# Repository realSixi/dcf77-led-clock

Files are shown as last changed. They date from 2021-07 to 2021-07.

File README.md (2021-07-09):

# DCF77 LED Clock

A visualization for the DCF77 signal using 2 WS2812 / Neopixel LED Rings (60 and 24 LEDs). The DCF77 Signal is received via a Websocket Stream.

The intention is *not* to simple show the current time, but to show the single (bit) signals of the DCF77 signal.

Find more Information about DCF77 at Wikipedia: https://en.wikipedia.org/wiki/DCF77

YouTube: ESP8266 Projekt: DCF77 Visualisierung (https://www.youtube.com/watch?v=JKQQ1zitYd8)\
Video: https://www.youtube.com/watch?v=JKQQ1zitYd8

## Visualization

In the picture below the time is 20:33 (or 8:33). The 'white' pixels show the current time in the style of an analog clock: Minutes are at 33 and the hours are between 8 and 9 - like the clock-indicator of an analog watch.

Every "Block" is shown in alternating colors (yellow / blue). E.g. the first yellow block is the one-block of minutes (here 0100 = 4, means after the full circle the next one part of minute is 4).

There are 3 bits that are used as parity bits (green pixels in the image).

The second is indicated with a slightly lighter / darker pixel that's moving (hard to see in a still image).

### Limitations

This implementation does *not* always show the correct time:
- the 'white' indicators are only refreshed after a full circle (as intended by dcf77 protocol), but only if the parity bits are correct.
- if a partity bit is wrong, the indications 'lags' behind the real time
- due the source is a websocket... wrong data is really rare ;)
- if the websocket connection is interrupted: you'll be timeless. grap yourself a coffee and relax ;)

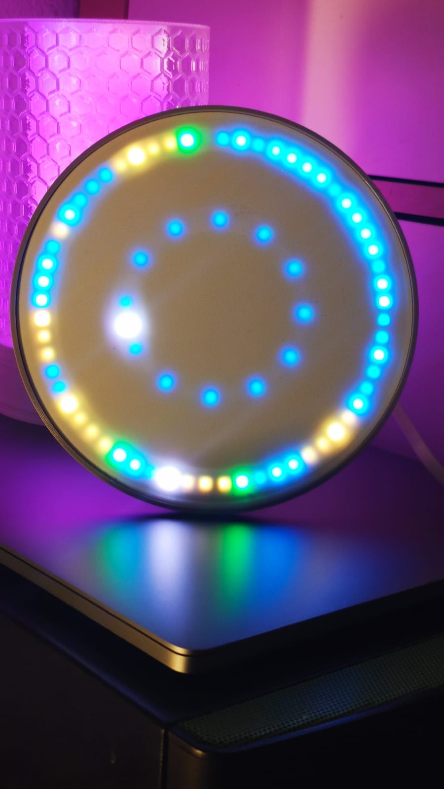
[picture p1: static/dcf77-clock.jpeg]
3D Printed Clock


## Hardware

### 3D Print

Find the STL Files in the [3D-Parts](./3d-parts) Folder. 

- Printed with a Prusa MK3S+ with PETG Filament and 0.6mm Nozzle
- The "Shader" is printed with white PETG 

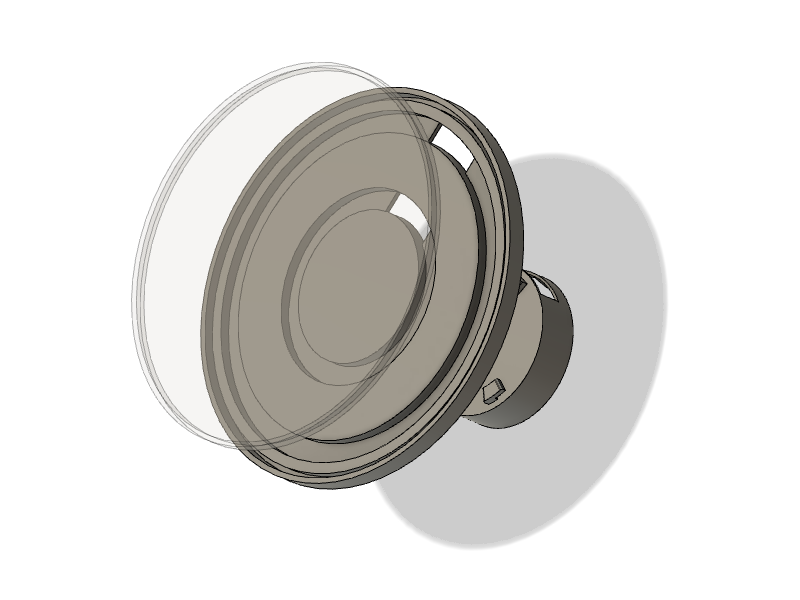
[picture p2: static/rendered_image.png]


### LEDs

There are multiple shops that deliver WS2812/Neopixel Rings (to Germany). Here is a short, uncomplete list. Just search for 'ws2812 ring' and you find a bunch of suppliers ;)

Solder the LED Rings together in a 'chain':
- LED 0-59 (the "minute" ring)
- LED 60-83 (the "hour" ring)

Data OUT of the large ring must be connected to Data IN of the small ring. Connect the Data IN Pin of the large ring to the ESP (default: D4) and the GNC/VCC accordingly.

#### 60 LED Ring

- https://www.funduinoshop.com/WS2812-LEDs-mit-60-Pixeln
- https://www.berrybase.de/sensoren-module/led/ws2812-13-neopixel/ringe/neopixel-ring-mit-60-ws2812-5050-rgb-leds
- https://de.aliexpress.com/w/wholesale-ws2812-ring-60.html

*Watch out! Some sellers offer only 1/4th of the Ring! So read the descriptions with care.*

#### 24 LED Ring

- https://www.funduinoshop.com/epages/78096195.sf/de_DE/?ObjectPath=/Shops/78096195/Products/F-5-3
- https://www.berrybase.de/sensoren-module/led/ws2812-13-neopixel/ringe/neopixel-ring-mit-24-ws2812-5050-rgb-leds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

## Software

### Setup

1. Rename the `credentials_example.h` in the root folder to `credentials.h` and set your WiFi credentials.
2. Set the LED_PIN if you use a different PIN than D4
3. Run with PlatformIO.

### Used Libraries / Tools

- PlatformIO http://platformio.org/
- FastLED: https://github.com/FastLED/FastLED
- WebSocket for Arduino: https://github.com/Links2004/arduinoWebSockets
- ArduinoJson: https://arduinojson.org/

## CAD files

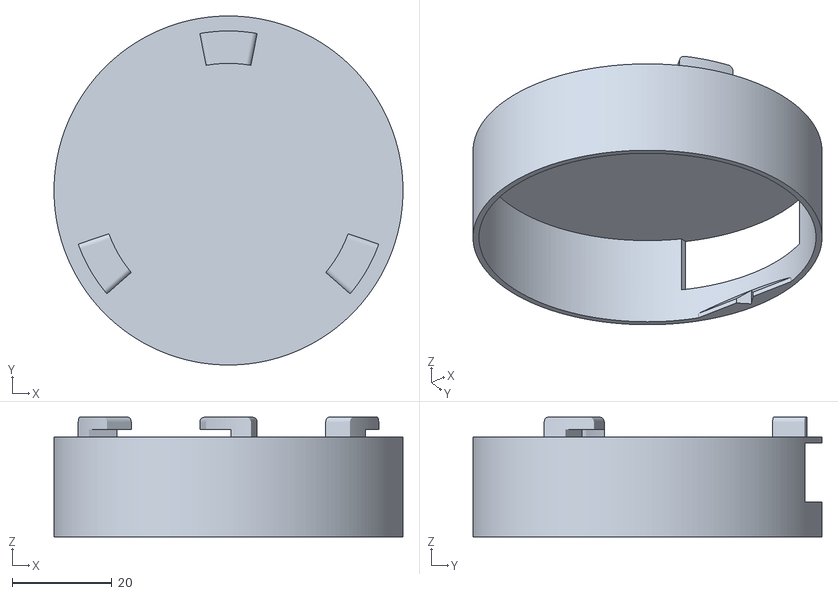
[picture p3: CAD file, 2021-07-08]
3d-parts/electronics_box.stl
70.0 x 70.0 x 24.0

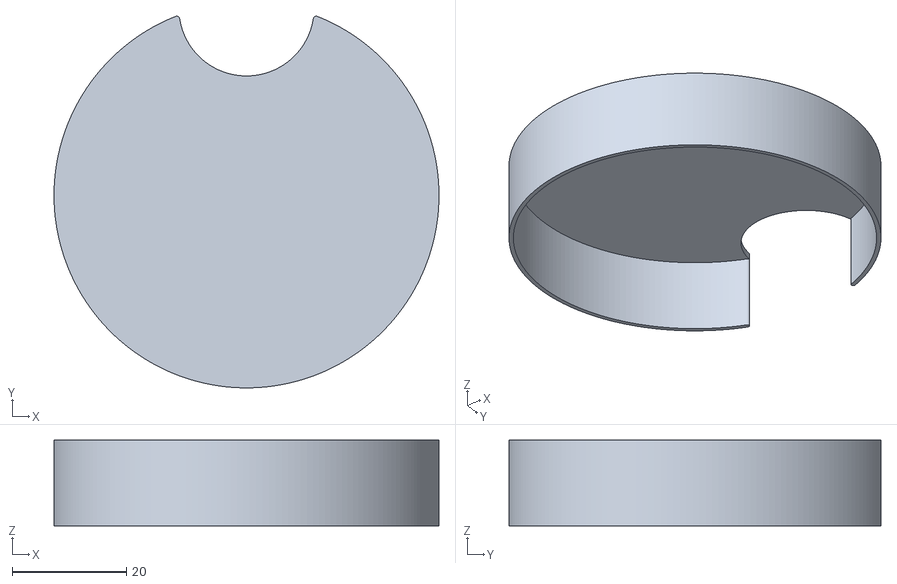
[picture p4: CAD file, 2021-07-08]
3d-parts/electronics_box_cap.stl
67.4 x 65.1 x 15.0

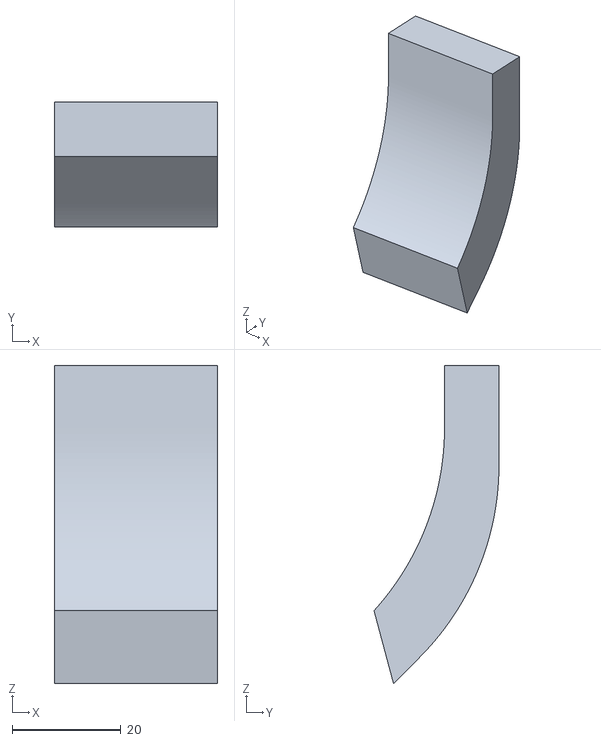
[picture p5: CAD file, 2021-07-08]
3d-parts/clock_desk_stand.stl
30.0 x 22.9 x 58.4

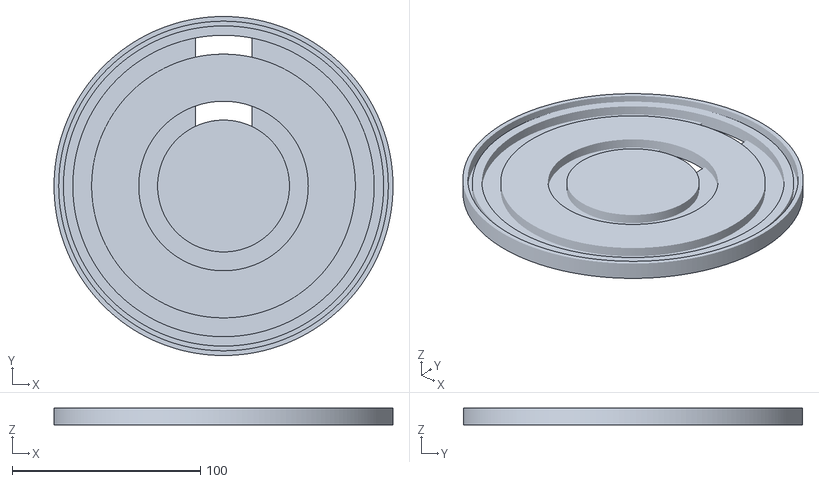
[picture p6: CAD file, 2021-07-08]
3d-parts/clock_led_holder.stl
180.0 x 180.0 x 9.00

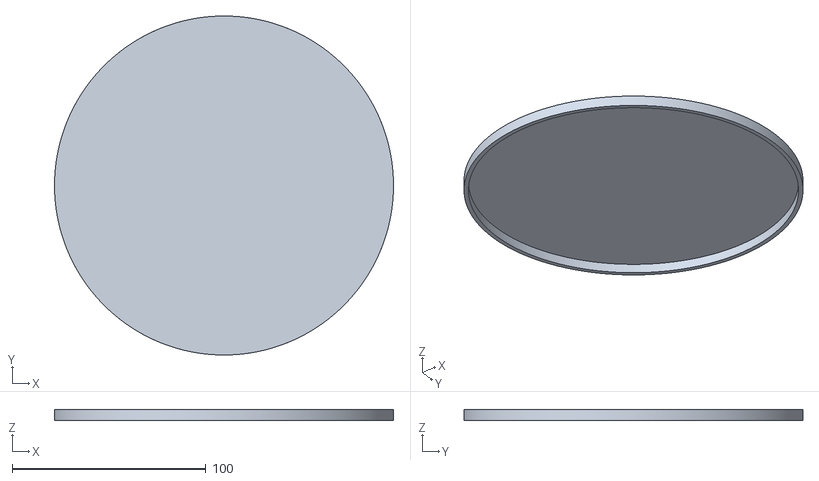
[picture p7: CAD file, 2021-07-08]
3d-parts/clock_shader.stl
174.8 x 174.8 x 5.60

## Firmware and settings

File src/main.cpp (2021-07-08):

#include <Arduino.h>
#include <ArduinoJson.h>
#include <ArduinoOTA.h>
#include <ESP8266WiFi.h>
#include <FastLED.h>
#include <WebSocketsClient.h>

#include "../credentials.h"
#include "dcf77.h"

DCF77Clock dcf77;

#define LED_PIN D4

#define MINUTE_LEDS 60
#define HOUR_LEDS 24

#define HUE_GROUP1 145
#define HUE_GROUP2 50

// ***************************
// function header definitions
// ***************************

void drawHour();
void drawPixel(int pos, int value);

void webSocketEvent(WStype_t type, uint8_t* payload, size_t length);

// some helper functions, see implementation at end of the file
void nblendU8TowardU8(uint8_t& cur, const uint8_t target, uint8_t amount);
CHSV fadeTowardColor(CHSV& cur, const CHSV& target, uint8_t amount);
CRGB sqrtBlend(CRGB a, CRGB b, uint8_t t);
CHSV sqrtBlend(CHSV a, CHSV b, uint8_t t);

/*
 *  we use 2 arrays:
 *  - "leds" is the normal array used by FastLED
 *  - "ledColors" is holding the current colors as HSV values for better
 * manipulation
 *
 *  sync from ledColors -> leds is being done at the end the drawPixel call
 */
CRGB leds[MINUTE_LEDS + HOUR_LEDS];
CHSV ledColors[MINUTE_LEDS];

WiFiClient wifi;
WebSocketsClient webSocket;

void setup() {
  Serial.begin(115200);
  Serial.println("Starting...");

  FastLED.addLeds<WS2812B, LED_PIN, GRB>(leds, MINUTE_LEDS + HOUR_LEDS);

  delay(100);
  FastLED.clear();
  FastLED.show();

  // setup wifi and show startup animation
  WiFi.hostname("DCFClock");
  WiFi.begin(WIFI_SSID, WIFI_PASSWORD);

  int connectionLed = 0;
  while (WiFi.status() != WL_CONNECTED) {
    Serial.print(".");
    leds[connectionLed] = CRGB::Red;

    fadeToBlackBy(leds, MINUTE_LEDS, 20);
    connectionLed = (connectionLed + 1) % MINUTE_LEDS;
    FastLED.show();
    FastLED.delay(20);
  }
  WiFi.hostname("DCFClock");

  ArduinoOTA.begin();

  Serial.println(" connected!");

  // setup websocket
  webSocket.beginSSL("www.dcf77logs.de", 443, "/ajax/liveview");
  webSocket.setReconnectInterval(5000);
  webSocket.onEvent(webSocketEvent);

  // initialize the shadow-led array
  for (int i = 0; i < MINUTE_LEDS; i++) {
    ledColors[i] = CHSV(0, 0, 0);
  }
}

void loop() {
  webSocket.loop();
  ArduinoOTA.handle();

  for (int i = 0; i < MINUTE_LEDS; i++) {
    drawPixel(i, dcf77.getBit(i));
  }
  drawHour();

  FastLED.show();
  FastLED.delay(10);
}

/*
 * calculate and set the color (hue, saturation and brightness)
 * based on the given position (0 to 60) and the value (0 or 1)
 * @see https://de.wikipedia.org/wiki/DCF77 for pixels and meanings
 */
void drawPixel(int pos, int value) {
  /*
   * calculate the hsv values depending on the position
   */

  int hue = 0;
  int sat = 255;
  int brightness = 0;

  // set the base brightness for on / off pixels
  if (value == 0) {
    brightness = 50;
  } else if (value == 1) {
    brightness = 140;
  }

  if (pos <= 20) {  // start bit, weather/warning informations and shift-second
                    // / timezone information; currently ignored
    hue = HUE_GROUP1;
  } else if (pos >= 21 && pos <= 24) {  // 1-part of minutes
    hue = HUE_GROUP2;
  } else if (pos >= 25 && pos <= 27) {  // 10-part of minutes
    hue = HUE_GROUP1;
  }

  else if (pos == 28) {  // parity of minutes
    hue = value == dcf77.parity(21, 27) ? 96 : 0;
  }

  else if (pos >= 29 && pos <= 32) {  // 1-part of hours
    hue = HUE_GROUP2;
  } else if (pos >= 33 && pos <= 34) {  // 10-part of hours
    hue = HUE_GROUP1;
  }

  else if (pos == 35) {  // parity of hours
    hue = value == dcf77.parity(29, 34) ? 96 : 0;
  }

  else if (pos >= 36 && pos <= 39) {  // 1-part of day
    hue = HUE_GROUP2;
  } else if (pos >= 40 && pos <= 41) {  // 10-part of day
    hue = HUE_GROUP1;
  }

  else if (pos >= 42 && pos <= 44) {  // weekday
    hue = HUE_GROUP2;
  }

  else if (pos >= 45 && pos <= 48) {  // 1-part of month
    hue = HUE_GROUP1;
  } else if (pos >= 49 && pos <= 49) {  // 10-part of month
    hue = HUE_GROUP2;
  }

  else if (pos >= 50 && pos <= 53) {  // 1-part of year
    hue = HUE_GROUP1;
  }

  else if (pos >= 54 && pos <= 57) {  // 10-part of year
    hue = HUE_GROUP2;
  }

  else if (pos == 58) {  // parity bit for date
    hue = value == dcf77.parity(36, 57) ? 96 : 0;
  }

  else if (pos == 59) {  // shift-second - not used
    brightness = 0;
  }

  else {  // default, should not appear
    brightness /= 2;
    hue = (310 / 360.) * 255;
    sat = 255;
  }

  /*
   * overwrite values for current and last position
   */

  if (pos == dcf77.getPosition()) {  // current received bit
    if (value == 0) {                // if value is 0 - blend to darker color
      ledColors[pos] = sqrtBlend(ledColors[pos], CHSV(hue, sat, 15), 10);
    } else {  // if value is 1 - blend to lighter color
      ledColors[pos] = sqrtBlend(ledColors[pos], CHSV(hue, 00, 255), 2);
    }
  } else if (pos == dcf77.getPosition() - 1) {
    // last bit, fade it to default set color/brightness
    ledColors[pos] = sqrtBlend(ledColors[pos], CHSV(hue, sat, brightness), 50);
  } else {  // set to calculated value
    ledColors[pos] = CHSV(hue, sat, brightness);
  }

  // sync the hsv value from ledColors to leds array
  leds[pos] = ledColors[pos];

  // overwrite the current minute with bright white color
  if (pos == dcf77.getRealMinutes()) {
    leds[pos] = CHSV(0, 0, 180);
  }
}

/*
 * handle websocket events and pass them to the dcf77 module
 */
void webSocketEvent(WStype_t type, uint8_t* payload, size_t length) {
  switch (type) {
    case WStype_DISCONNECTED:
      Serial.printf("[WSc] Disconnected!\n");
      break;
    case WStype_CONNECTED: {
      Serial.printf("[WSc] Connected to url: %s\n", payload);
    } break;
    case WStype_TEXT: {
      StaticJsonDocument<200> doc;
      deserializeJson(doc, payload);

      if (doc["Type"] == 1) {
        int pulseLength = doc["Pulse"].as<int>();
        int pause = doc["Pause"].as<int>();
        dcf77.handlePulse(pulseLength, pause);
      }

      break;
    }
    case WStype_BIN:
      Serial.printf("[WSc] get binary length: %u\n", length);
      break;
    case WStype_PING:
      Serial.printf("[WSc] get ping\n");
      break;
    case WStype_PONG:
      Serial.printf("[WSc] get pong\n");
      break;
    case WStype_ERROR:
      Serial.printf("[WSc] got Error\n");
  }
}

/*
 * draw the current (real) hour to the inner circle
 * and the base 'clock' indicators
 */
void drawHour() {
  int realHour = dcf77.getRealHours();
  int realMinutes = dcf77.getRealMinutes();

  // if minutes are greater than 20, set the led between the hours on
  int led = (realHour * 2) % 24;
  if (realMinutes > 20) {
    led++;
  }
  // if minutes are greater than 40, set the led for the next hour to on
  if (realMinutes > 40) {
    led++;
  }

  led = led % HOUR_LEDS;

  // draw the clock indicators
  for (int i = 0; i <= HOUR_LEDS; i += 2) {
    if (i != led) {
      leds[i + MINUTE_LEDS] = CHSV(145, 255, 50);
    }
  }

  // slowly fade down all clock-leds for transition
  for (int i = MINUTE_LEDS; i <= HOUR_LEDS + MINUTE_LEDS; i++) {
    leds[i].fadeToBlackBy(10);
  }

  // set the led for the realHour
  if (realHour != -1) {
    leds[led + MINUTE_LEDS] = CHSV(255, 0, 180);
  }
}

// some helper functions for color fading / blending

void nblendU8TowardU8(uint8_t& cur, const uint8_t target, uint8_t amount) {
  if (cur == target) return;

  if (cur < target) {
    uint8_t delta = target - cur;
    delta = scale8_video(delta, amount);
    cur += delta;
  } else {
    uint8_t delta = cur - target;
    delta = scale8_video(delta, amount);
    cur -= delta;
  }
}

// Blend one CRGB color toward another CRGB color by a given amount.
// Blending is linear, and done in the RGB color space.
// This function modifies 'cur' in place.
CHSV fadeTowardColor(CHSV& cur, const CHSV& target, uint8_t amount) {
  nblendU8TowardU8(cur.hue, target.hue, amount);
  nblendU8TowardU8(cur.sat, target.sat, amount);
  nblendU8TowardU8(cur.val, target.val, amount);
  return cur;
}

CRGB sqrtBlend(CRGB a, CRGB b, uint8_t t) {
  CRGB rgb;

  rgb.r = sqrt16(scale16by8(a.r * a.r, (255 - t)) + scale16by8(b.r * b.r, t));
  rgb.g = sqrt16(scale16by8(a.g * a.g, (255 - t)) + scale16by8(b.g * b.g, t));
  rgb.b = sqrt16(scale16by8(a.b * a.b, (255 - t)) + scale16by8(b.b * b.b, t));

  return rgb;
}

CHSV sqrtBlend(CHSV a, CHSV b, uint8_t t) {
  CHSV hsv;

  hsv.h = sqrt16(scale16by8(a.h * a.h, (255 - t)) + scale16by8(b.h * b.h, t));
  hsv.s = sqrt16(scale16by8(a.s * a.s, (255 - t)) + scale16by8(b.s * b.s, t));
  hsv.v = sqrt16(scale16by8(a.v * a.v, (255 - t)) + scale16by8(b.v * b.v, t));

  return hsv;
}

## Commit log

2021-07-08 add readme, images + STL files
    [clock_desk_stand.stl, clock_led_holder.stl, clock_shader.stl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]
2021-07-08 fix hour-overflow, show realTime only if at least time is synced completely, fix dependencies
    [main.cpp]
